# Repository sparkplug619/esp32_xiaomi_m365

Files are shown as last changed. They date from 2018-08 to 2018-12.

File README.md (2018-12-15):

attention - last update of this repo - i moved it to gitlab -> https://gitlab.com/esp32m365/esp32_xiaomi_m365_display

# esp32_xiaomi_m365
Sample Project for decoding serial bus data on a Xiaomi M365 Scooter on Espressif ESP32:
- Supports one or two 0.96" 128x64 SSD1306 based OLED screen(s)
- Display connectivity via i2c or spi (spi preffered as it's much faster)
- Firmwareupdates (of the ESP32) can be done over WiFi using ArduinoOTA, Scooterfirmwareupdates are not blocked, can be done the usual way
- Connects to known WiFi Networks or opens it's own SSID in AP Mode
- optional Telnet Servers for debugging
- Config Menu for changing scooter & esp settings
- Supports different Screen Languages, Miles/Kilometers, Wheel Sizes, 10/12s batteries
- Alerts for Low Battery, ESC, BMS Temperature, Cell-Voltage Monitoring,...
- displays speeds above 32.768km/h (set for speeds from 10km/h backwards to 55,44km/h forward, backwardspeed is displayed as a positive number)

# Details
- Telnet on Port 36523 with different Screens
- Telnet on Port 36524 with raw byte dump from M365 Bus ("read only")
- Telnet on Port 36525 with packet decode/dump from M365 Bus ("read only")
- M365 Serial Receiver and Packet decoder into Array per Address
- M365 Data Requestor obey the M365 Bus Timing, does not interfere with Xiaomi's Firmware-Flash process, but can be disabled in the menu (ESP Bus Mode = Passive)
- Data Requestor internally allows subscription to predefined groups of data (e.g. OLED display only needs Cell-Voltage Data when it's displayed) to reduce requested data and therefore get a higher update rate on the interesting data fields.
- Internal Timers/Counters for debugging Receiver/Requestor & Oled-Draw/Transfer Durations - see Telnet/36523 Statistics Screen
- Different Screens for Drive/Stop/Charge/Error/Firmwareupgrade/Locked State/Timeout-Screen
- Alerts: Background Task ("Housekeeper") periodically requests additional data from M365 and validates against tresholds (set in configmenu), shows alert-popup and increases alert-counters
- Popups on screen if alerts occur, alert-counters in data screens when stopped
- Scooter can be locked/unlocked/switched off from config-menu
- Custom Screens for
	- Driving
	- "Stopped" - multiple Data screens when not moving (swipe through them using throttle)
	- "Charging" - in single-screen configuration multiple screens while charging (swipe through them using throttle)
	- Config Menu (push Brake & Throttle at the same time to enter, select items using throttle, change/enter using brake)
 	- "LOCKED" screen mode when scooter has been locked

# Todos
 - add display-sleeptimer - x seconds after last event (gas/brake/throttle/speed/chargerun-plug/telnet/AP-Client Connection & speed = 0)

# Telnet / Debugging Interface
 - Telemetrie Screen shows decoded known values: Batt Voltage, Current, Speed,... 
 - Statistics Screen dumps some internal counters, e.g. Packet Counters, CRC Files, Timing,...
 - ESC/BLE/BMS/"X1" RAW Screens dumps the 512 Byte Array for each device (format "00 00 ...")

 use the letters
  - s,t,e,b,n,x to switch between the screens
  - r to reset statistics & zero m365 data arrays

# Wiring
## Connector in M365 Headunit
M365 has a Serial Data Bus over one Wire (UART in half-duplex mode) between BLE Module and ESC (Motor Controller) and we want to connect the ESP32 to that bus, as well as get Power from the Scooter.
The Connection between BLE-Module and ESC consists of 4 wires, the connection as seen on the BLE Module:
- Ground  (Black, "G")
- One Wire Serial Connection (Yellow, "T", 115200bps, 8n1)
- VBatt (Green, "P", always available)
- 5V (Red, "5", only when scooter is turned on)

## ESP32 Powering
ESP32 needs a Vcc of 3.3V, so you can wire the 5V from M365 to a Vreg for 3.3v which powers the ESP. DO NOT POWER THE ESP32 WITH 5V!

## M365 Serial Data Bus Connection

Other then the VCC which can not be 5V, the ESP32 GPIO Pins can be connected to 5V signals.
So the Serial RX & TX Pins can be directly connected, but to ensure communication on the one-wire uart bus we need 2, to be on the safe side 3 parts:
 - 680R or 1k between RX and M365 Data Bus
 - And a Diode from M365 Data Bus in series with a ~100-200R towards TX Pin of  ESP32
That way Hardware-UART on the ESP32 can be used.

## ESP32 Pin assignment

The ESP32 has a io-switchmatrix, so (nearly) any hardwareunit can be mapped to nearly any pin.
Just be sure to not to use:
 - GPIO_NUM_34 – GPIO_NUM_39 are only GPI - Input, NO OUTPUT, No Pullup or Pulldown!
 - GPIO 6-11 are used by flash - not usable
 - GPIO 0 is for boot/flashing with pullup

# PCB Bugs v180723
 - 1nF or 470pF C from EN towards GND and 12-18k R from EN towards 3.3V are missing (sad copy and paste error)
 - the SOT23 Diode housing might be wrong - depending on your Diode (BAS70xx versions) -> the Diode-Package can be rotated 120° CCW to fix that

# Before Compiling

## Choose your environment  (platformio):
  - PlatformIO supports different (build-)"Environments", you will mostly want to select "m365client" which implements the "client" for a stock m365 scooter and the oled display.
## PATCH your libraries!
  - Plattformio includes my patched Adafuit_SSD1306 library for you, if u are using a different ide, please look in platformio.ini for references to the patches libraries and make sure those are used. In the meanwhile Adafruit updated it's libraries to get rid of the problems, so one day i'll update my code to use the new lib from Adafruit and get rid of the patched libraries.
  - earlier code versions needed some files patched in arduino-esp32 framework in order for correct uart functionality. now i've included the patched UART-Files in this repo, so the patch in arduino-esp32 is not needed anymore (save you time and solves the problem that your other projects would also use that patched framework). But one day when arduino-esp32 framework get's updated this might brake and the files included in this project need to be updated.
  - unfortunately the latest update of platform-io included the arduino-esp32 framework with a broken i2c implementation. This needs to be patched manually, but it fixes a general problem, so this will help your other projects using i2c as well. For patching please see this issue and replace the 4 files as mentioned - otherwise the i2c-display will hang at most restarts: https://github.com/platformio/platform-espressif32/issues/126

## setup individual settings
### ssid's and passwords:
 - please open secrets.h and fill in your own ssid/passwords for client/ap mode and ota updates!
### setup for your hardware
 - copy one of my board*.h files that fits your hardware best, update it for your setup and include this file in definitions.h
 - when updating my code you just need to reapply the include of your boards file in definitions.h

# Support, Questions,...?
 - Telegram Group https://t.me/esp32brain4m365

# Credits & Thanks to
 - Paco Gorina for his research on the protocoll and packet structure (-> http://www.gorina.es/9BMetrics/)
 - CamiAlfa for his research and providing informations about the contents of the packets & arrays (-> https://github.com/CamiAlfa/M365-BLE-PROTOCOL)
 - french translation kindly provided by Technoo' Loggie (Telegram Handle @TechnooLoggie)

# Licensed under Creative Commons V4 - BY NC SA
 - THIS MEANS YOU CAN USE THIS CODE FOR NON COMMERCIAL PURPOSES, HAVE TO RESHARE YOUR MODIFICATIONS AND REFERENCE THIS REPO.

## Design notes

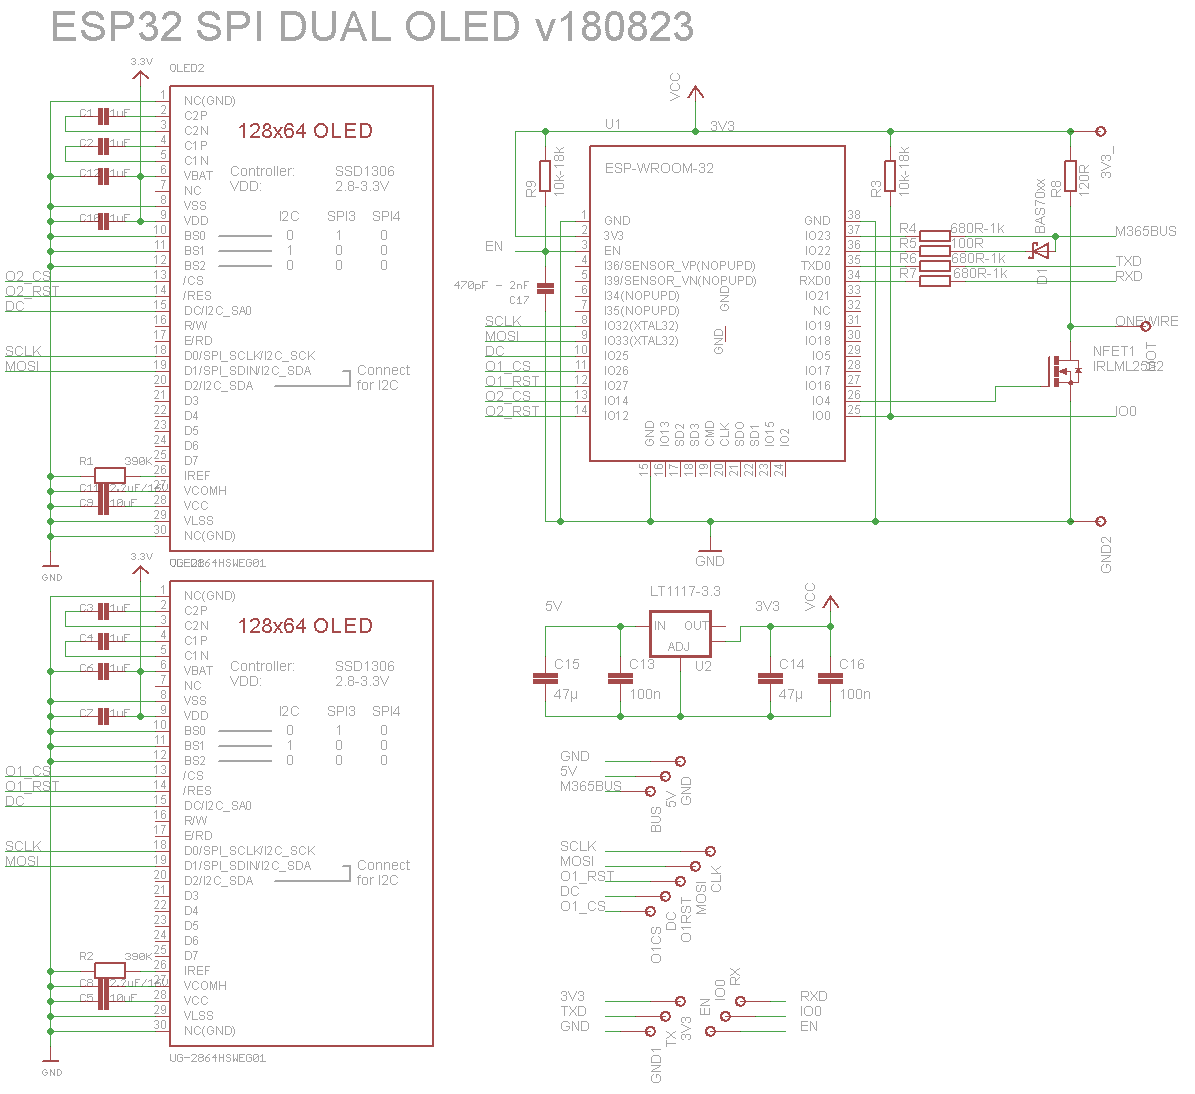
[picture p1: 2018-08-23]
schematics/esp32_ssd1306_schematic_v180823.png

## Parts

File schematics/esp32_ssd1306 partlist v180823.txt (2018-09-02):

Exported from esp32_ssd1306.sch v180823

Part     Value          Device                        Package                          Library              Sheet

ESP32:
U1       ESP-WROOM-32   ESP-WROOM-32                  ESP-WROOM-32                     esp32                1
R6       680R-1k        R-EU_R0805                    R0805                            rcl                  1
R7       680R-1k        R-EU_R0805                    R0805                            rcl                  1
R3       10k-18k        R-EU_R0805                    R0805                            rcl                  1
R9       10k-18k        R-EU_R0805                    R0805                            rcl                  1
C17      470pF - 2nF    CAP_CERAMIC0805               0805                             microbuilder         1

Voltage Regulator:
U2       LT1117-3.3     V_REG_LM1117SOT223            SOT223                           SparkFunEagle-6-6-07 1
C13      100n           C-EUC0805K                    C0805K                           rcl                  1
C14      47µ            C-EUC1210K                    C1210K                           rcl                  1
C15      47µ            C-EUC1210K                    C1210K                           rcl                  1
C16      100n           C-EUC0805K                    C0805K                           rcl                  1

M365 Connection:
R4       680R-1k        R-EU_R0805                    R0805                            rcl                  1
R5       100R           R-EU_R0805                    R0805                            rcl                  1
D1       BAS70xx        BAS70                         SOT23                            diode                1

Needed for OLED Display Connector soldered directly to PCB on Connector OLED1:
OLED1    UG-2864HSWEG01 DISP_OLED_UG-2864HSWEG010.96" UG-2864HSWEG01_0.96IN_WRAPAROUND ssd1306              1
R2       390K           RESISTOR0805                  0805                             microbuilder         1
C3       1uF            CAP_CERAMIC0805               0805                             microbuilder         1
C4       1uF            CAP_CERAMIC0805               0805                             microbuilder         1
C6       1uF            CAP_CERAMIC0805               0805                             microbuilder         1
C7       1uF            CAP_CERAMIC0805               0805                             microbuilder         1
C5       10uF           CAP_CERAMIC0805               0805                             microbuilder         1
C8       2.2uF/16V      CAP_CERAMIC0805               0805                             microbuilder         1

Needed for OLED Display Connector soldered directly to PCB on Connector OLED2:
OLED2    UG-2864HSWEG01 DISP_OLED_UG-2864HSWEG010.96" UG-2864HSWEG01_0.96IN_WRAPAROUND ssd1306              1
R1       390K           RESISTOR0805                  0805                             microbuilder         1
C1       1uF            CAP_CERAMIC0805               0805                             microbuilder         1
C2       1uF            CAP_CERAMIC0805               0805                             microbuilder         1
C12      1uF            CAP_CERAMIC0805               0805                             microbuilder         1
C9       10uF           CAP_CERAMIC0805               0805                             microbuilder         1
C10      1uF            CAP_CERAMIC0805               0805                             microbuilder         1
C11      2.2uF/16V      CAP_CERAMIC0805               0805                             microbuilder         1

Optional (not implemented in Firmware) for Temperature Sensor (1-wire or analog):
NFET1    IRLML2502      IRLML2502                     MICRO3                           transistor-power     1
R8       120R           R-EU_R0805                    R0805                            rcl                  1

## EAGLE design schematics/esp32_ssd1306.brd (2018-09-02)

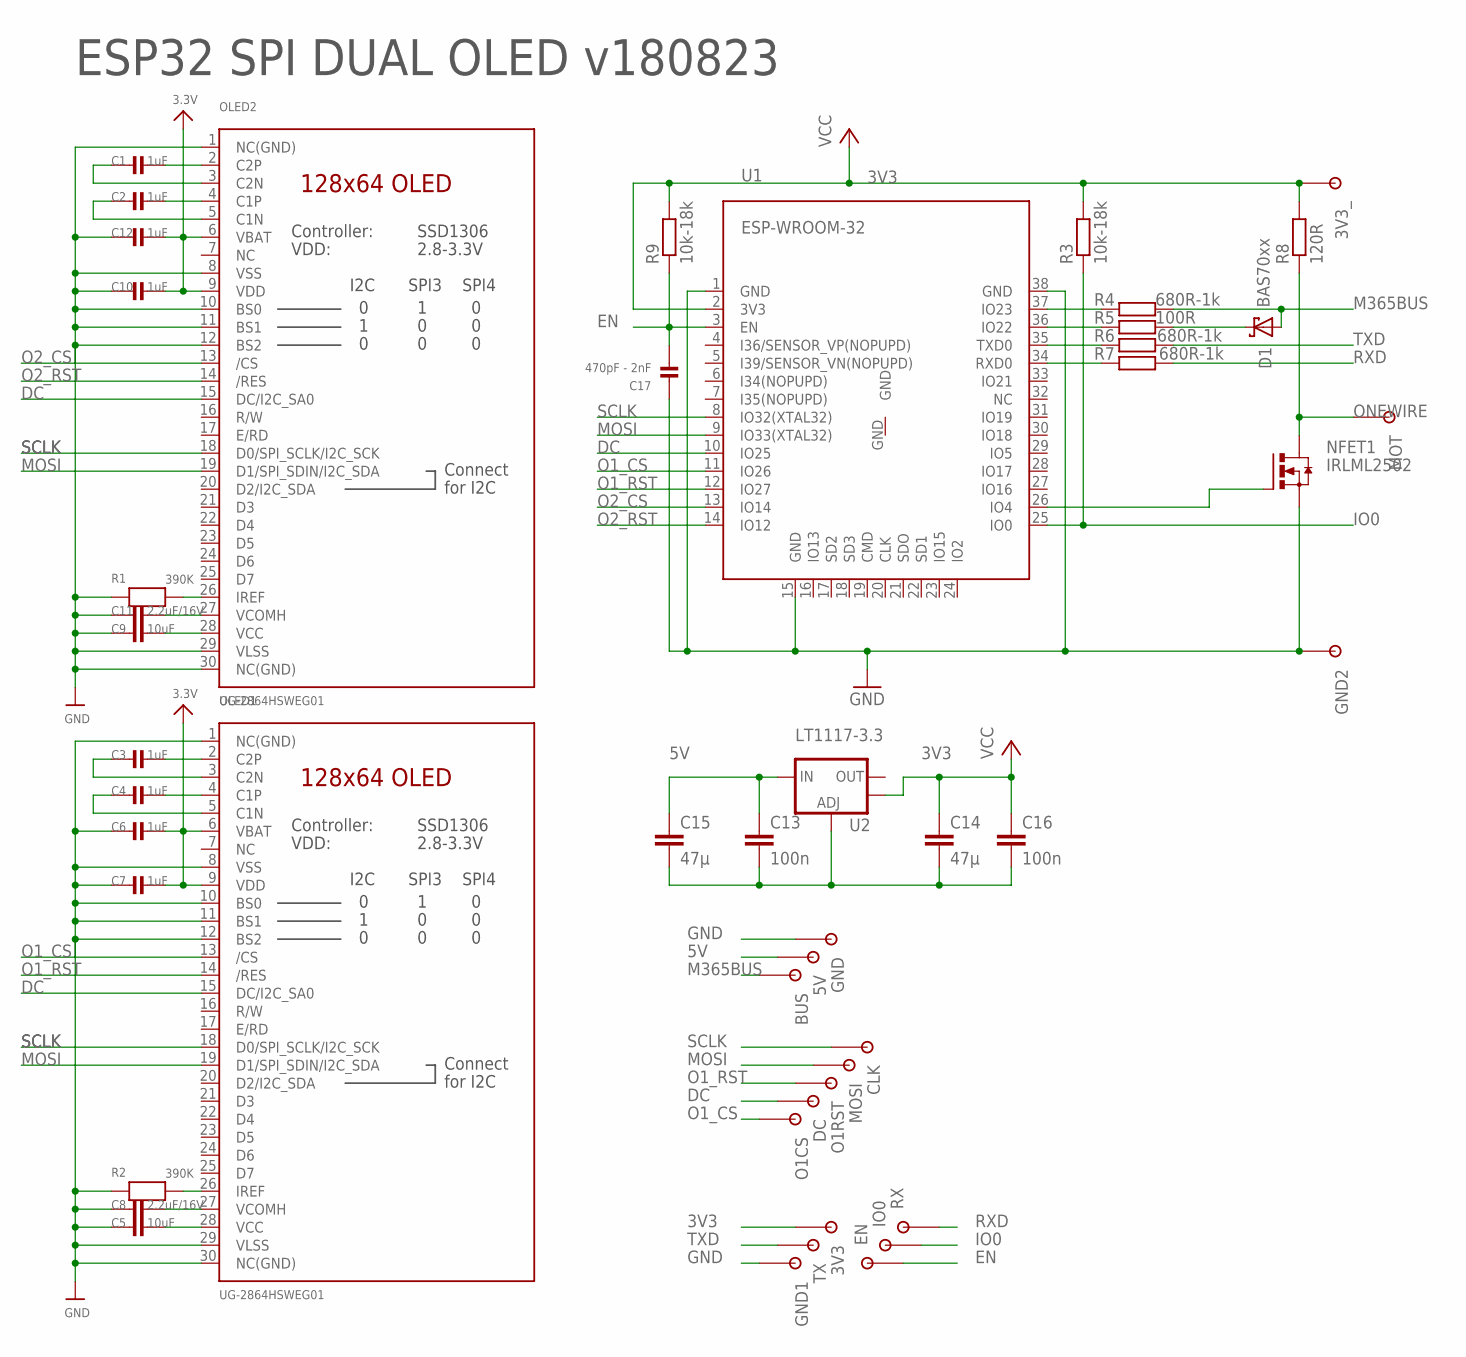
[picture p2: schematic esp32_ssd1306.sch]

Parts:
3V3, 3V3_, 5V: PAD1
BUS: PAD1
C1, C2, C3, C4, C6, C7, C10, C12: 1uF; 0805
C5, C9: 10uF; 0805
C8, C11: 2.2uF/16V; 0805
C13, C16: 100n; C0805K
C14, C15: 47µ; C1210K
C17: 470pF - 2nF; 0805
CLK: PAD1
D1: BAS70xx; SOT23
DC: PAD1
EN: PAD1
GND, GND1, GND2: PAD1
IO0: PAD1
MOSI: PAD1
MOT: PAD1
NFET1: IRLML2502; MICRO3
O1CS, O1RST: PAD1
OLED1, OLED2: UG-2864HSWEG01; UG-2864HSWEG01_0.96IN_WRAPAROUND
R1, R2: 390K; 0805
R3, R9: 10k-18k; R0805
R4, R6, R7: 680R-1k; R0805
R5: 100R; R0805
R8: 120R; R0805
RX: PAD1
TX: PAD1
U1: ESP-WROOM-32
U2: LT1117-3.3; SOT223

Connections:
3V3: 3V3.P$1, 3V3_.P$1, C6.2, C7.2, C10.2, C12.2, C14.1, C16.1, OLED1.6 (VBAT), OLED1.9 (VDD), OLED2.6 (VBAT), OLED2.9 (VDD), R3.2, R8.2, R9.2, U1.2 (3V3), U2.4 (OUT)
5V: 5V.P$1, C13.1, C15.1, U2.3 (IN)
DC: DC.P$1, OLED1.15 (DC/I2C_SA0), OLED2.15 (DC/I2C_SA0), U1.10 (IO25)
EN: C17.2, EN.P$1, R9.1, U1.3 (EN)
GND: C5.1, C6.1, C7.1, C8.1, C9.1, C10.1, C11.1, C12.1, C13.2, C14.2, C15.2, C16.2, C17.1, GND.P$1, GND1.P$1, GND2.P$1, NFET1.2 (S), OLED1.1 (NC(GND)), OLED1.8 (VSS), OLED1.10 (BS0), OLED1.11 (BS1), OLED1.12 (BS2), OLED1.29 (VLSS), OLED1.30 (NC(GND)), OLED2.1 (NC(GND)), OLED2.8 (VSS), OLED2.10 (BS0), OLED2.11 (BS1), OLED2.12 (BS2), OLED2.29 (VLSS), OLED2.30 (NC(GND)), R1.1, R2.1, U1.1 (GND), U1.15 (GND), U1.38 (GND), U2.1 (ADJ)
IO0: IO0.P$1, R3.1, U1.25 (IO0)
M365BUS: BUS.P$1, D1.1 (A), R4.2
MOSI: MOSI.P$1, OLED1.19 (D1/SPI_SDIN/I2C_SDA), OLED2.19 (D1/SPI_SDIN/I2C_SDA), U1.9 (IO33(XTAL32))
unnamed: OLED2.26 (IREF), R1.2
unnamed: C1.2, OLED2.2 (C2P)
unnamed: OLED1.26 (IREF), R2.2
unnamed: C3.2, OLED1.2 (C2P)
unnamed: C3.1, OLED1.3 (C2N)
unnamed: C4.2, OLED1.4 (C1P)
unnamed: C4.1, OLED1.5 (C1N)
unnamed: C1.1, OLED2.3 (C2N)
unnamed: C2.2, OLED2.4 (C1P)
unnamed: C2.1, OLED2.5 (C1N)
unnamed: C5.2, OLED1.28 (VCC)
unnamed: C8.2, OLED1.27 (VCOMH)
unnamed: C9.2, OLED2.28 (VCC)
unnamed: C11.2, OLED2.27 (VCOMH)
unnamed: D1.3 (C), R5.2
unnamed: NFET1.1 (G), U1.26 (IO4)
unnamed: R4.1, U1.37 (IO23)
unnamed: R5.1, U1.36 (IO22)
unnamed: R6.1, U1.35 (TXD0)
unnamed: R7.1, U1.34 (RXD0)
O1_CS: O1CS.P$1, OLED1.13 (/CS), U1.11 (IO26)
O1_RST: O1RST.P$1, OLED1.14 (/RES), U1.12 (IO27)
O2_CS: OLED2.13 (/CS), U1.13 (IO14)
O2_RST: OLED2.14 (/RES), U1.14 (IO12)
ONEWIRE: MOT.P$1, NFET1.3 (D), R8.1
RXD: R7.2, RX.P$1
SCLK: CLK.P$1, OLED1.18 (D0/SPI_SCLK/I2C_SCK), OLED2.18 (D0/SPI_SCLK/I2C_SCK), U1.8 (IO32(XTAL32))
TXD: R6.2, TX.P$1

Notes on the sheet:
ESP32 SPI DUAL OLED v180823

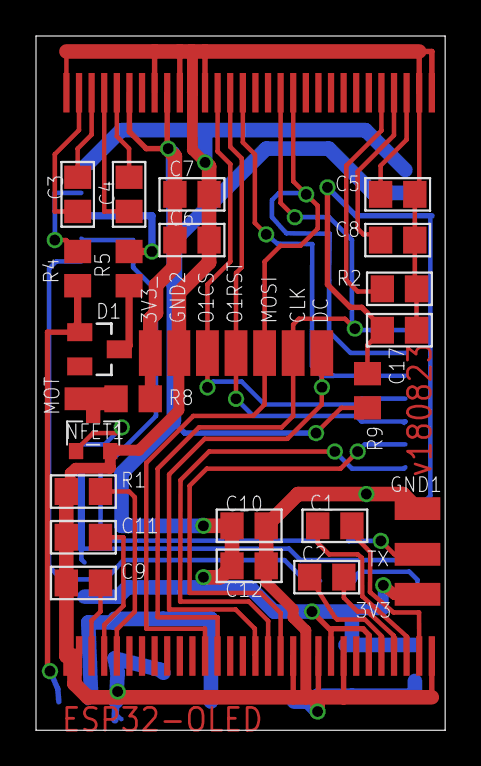
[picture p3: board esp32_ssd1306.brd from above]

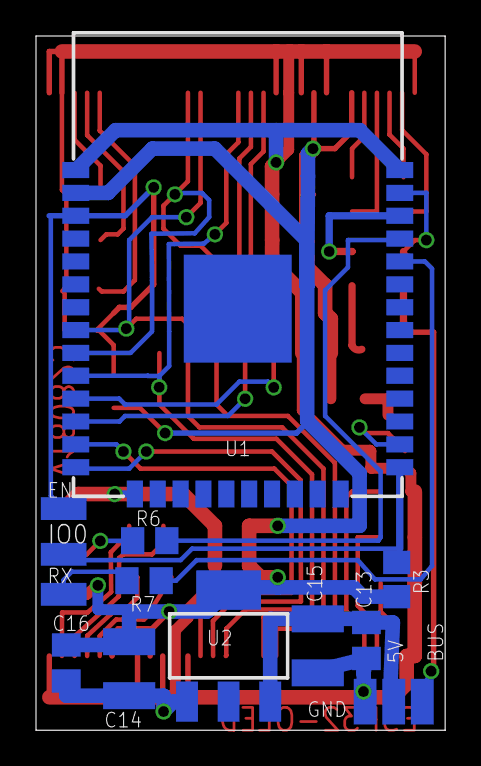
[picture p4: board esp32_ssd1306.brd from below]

Board: 2 copper layers, 22.7 x 38.6 mm, 49 parts (17 on the bottom side), 36 nets.

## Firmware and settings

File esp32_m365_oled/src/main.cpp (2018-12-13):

/*  ESP32 M365
 * see readme.md for details
 *
 * configuration adoptions should be done in definitions.h
 * secrets.h must be created (see readme.md)
 * boards.h can be created to store your hardware-setup locally and keep it when updates are rolling in (see readme.md)
 * language adoptions in strings.h - i'm happy to add new languages/translations from you ;)
 *
 * needs patch in esp32-arduino-core/esp32-hal-uart.c (112 byte hardware uart-receive buffer is to big for "realtime" communication)
 *  -> see comments in definitions.h / readme.md and patch yourself or use https://github.com/smartinick/arduino-esp32
 * for now this has to be done locally on your dev machine
 *
 * needs patched Adafruit_SSD1306 Library (patched fork see https://github.com/smartinick/Adafruit_SSD1306)
 * platformio.ini is configured to use this library - no user interaction needed
 *
 * known BUGS: 
 * - apssid/appassword not applied when switching from client-mode/search to AP
 * - does not receive/decode all data after doing OTA, reboot once and it works
 * - "beep" command does not work in current version
 */

#include "definitions.h"
#include "config.h"
#include "strings.h"
#include "wlan.h"
#ifdef headunit
  #include "m365headunit.h"
#else
  #include "m365client.h"
#endif
#ifdef usedisplay
  #include "display.h"
#endif
#ifdef usengcode
  #include "ngcode.h"
#endif
#ifdef usetelnetserver
  #include "telnet.h"
#endif

#ifdef usestatusled
  int ledontime = 0;
  int ledofftime = 10000;
  unsigned long ledcurrenttime = 100;
#endif

//generic temp  vars
  uint8_t i;
  char tmp1[200];
  char tmp2[200];

//timing & statistics
  unsigned long duration_mainloop=0;
  unsigned long timestamp_mainloopstart=0;
  unsigned long duration_oled=0;
  unsigned long timestamp_oledstart=0;
  unsigned long duration_oled1draw=0;
  unsigned long timestamp_oled1draw=0;
  unsigned long duration_oled1transfer=0;
  unsigned long timestamp_oled1transfer=0;
  unsigned long duration_oled2draw=0;
  unsigned long timestamp_oled2draw=0;
  unsigned long duration_oled2transfer=0;
  unsigned long timestamp_oled2transfer=0;
  unsigned long duration_telnet=0;
  unsigned long timestamp_telnetstart=0;
  unsigned long timestamp_showsplashscreen=0;

HardwareSerialPatched m365uart(2);

boolean pcflag = true;

#ifdef headunit
  M365Headunit *ptrm365bus = new M365Headunit();
#else
  M365Client *ptrm365bus = new M365Client();
#endif
#ifdef usedisplay
  M365Display *ptrm365d = new M365Display();
#endif

/*
//define
      #define throttlemindefault 40
      #define throttlemaxdefault 190
      uint8_t throttlemin = throttlemindefault;
      uint8_t throttlemax = throttlemaxdefault;


//setup:
  

//loop: if newdata from "x1"
  from updatestats:
    1st block
      if (bleparsed->throttle!=0) {
        if (throttlemin>bleparsed->throttle) { 
          throttlemin=bleparsed->throttle; 
          stopwindowsize = (uint8_t)((throttlemax-throttlemin)/stopsubscreens);
          chargewindowsize = (uint8_t)((throttlemax-throttlemin)/chargesubscreens);
          configwindowsize = (uint8_t)((throttlemax-throttlemin)/(configsubscreens-1));
        }
        if (throttlemax<bleparsed->throttle) { 
          throttlemax=bleparsed->throttle;
          stopwindowsize = (uint8_t)((throttlemax-throttlemin)/stopsubscreens);
          chargewindowsize = (uint8_t)((throttlemax-throttlemin)/chargesubscreens);
          configwindowsize = (uint8_t)((throttlemax-throttlemin)/(configsubscreens-1));
        }
      }
    2nd block:
      if (alert_lockedalarm)
          alertpopup((char*)"ALARM", (char*)"SCOOTER LOCKED!", popupalertduration);
      }
  



*/
#ifdef usestatusled
  void handle_led() {
    if (ledontime==0) { 
      digitalWrite(led,LOW); 
    } else {
      if (ledofftime==0) { 
        digitalWrite(led,HIGH); 
      } else {
        if (millis()>ledcurrenttime) {
          if (digitalRead(led)) {
            digitalWrite(led,LOW);
            ledcurrenttime = millis()+ledontime;
          } else {
            digitalWrite(led,HIGH);
            ledcurrenttime = millis()+ledofftime;
          } //else digitalread
        } //if millis
      } //else ledoff
    } //else ledon
  }//handle_led
#endif

#ifdef debug_dump_states //dump state machine states to Serial Port on change
  void print_states() {
    #ifdef usetelnetserver    
      if (telnetstate!=telnetstateold) {
        DebugSerial.printf("### TELNETSTATE %d -> %d\r\n",telnetstateold,telnetstate);
        telnetstateold=telnetstate;
      }
    #endif    
    if (ptrm365bus->m365receiverstate!=ptrm365bus->m365receiverstateold) {
      DebugSerial.printf("### M365RecState: %d -> %d\r\n",ptrm365bus->m365receiverstateold,ptrm365bus->m365receiverstate);
      ptrm365bus->m365receiverstateold=ptrm365bus->m365receiverstate;
    }
    if (ptrm365bus->m365packetstate!=ptrm365bus->m365packetstateold) {
      DebugSerial.printf("M365PacketState: %d -> %d\r\n",ptrm365bus->m365packetstateold,ptrm365bus->m365packetstate);
      ptrm365bus->m365packetstateold=ptrm365bus->m365packetstate;
    }    
  } //print_states
#endif

void printconfiguration() {
  DebugSerial.println("Using ESP32 Configuration:");
  #ifdef usengfeatuart
    DebugSerial.printf("# UART Mode: IO/1/2: %d/%d/%d\r\n",M365SerialGPIO, M365SerialSpareRX, M365SerialSpareTX);
  #else
    DebugSerial.printf("# UART Mode: RX/TX: %d/%d\r\n",UART2RX, UART2TX);
  #endif
  #ifdef usedisplay
    DebugSerial.println("# Display Configuration"); 
      #ifdef LANGUAGE_EN
        DebugSerial.println("#  Language: English");
      #endif
      #ifdef LANGUAGE_FR
        DebugSerial.println("#  Language: French");
      #endif
      #ifdef LANGUAGE_DE
        DebugSerial.println("#  Language: German");
      #endif
      #ifdef usei2c
        DebugSerial.printf("#  Mode: I2C, SDA: %d, SCL: %d, Reset: %d, doReset: %d, Clock: %lu\r\n", oled_sda, oled_scl,oled_reset, oled_doreset, oled_clock);
        #ifdef useoled1
          DebugSerial.printf("#  display1: Address: 0x%02x, Rotation: %d\r\n", oled1_address, OLED1_ROTATION);
        #endif
        #ifdef useoled2
          DebugSerial.printf("#  display2: Address: 0x%02x, Rotation: %d\r\n", oled2_address, OLED2_ROTATION);
        #endif
      #else
        DebugSerial.printf("#  Mode: SPI, MiSo: %d, MoSi: %d, Clk: %d, DC: %d, Clock: %lu\r\n", OLED_MISO,OLED_MOSI,OLED_CLK,OLED_DC,oled_clock);
        #ifdef useoled1
          DebugSerial.printf("#  display1: CS: %d, Rst: %d, Rotation: %d\r\n", OLED1_CS, OLED1_RESET, OLED1_ROTATION);
        #endif
        #ifdef useoled2
          DebugSerial.printf("#  display2: CS: %d, Rst: %d, Rotation: %d\r\n", OLED2_CS, OLED2_RESET, OLED2_ROTATION);
        #endif
      #endif
    DebugSerial.printf("#  Display Core %d, Prio %d\r\n",core_display,prio_display);
  #else
    DebugSerial.println("# Display disabled"); 
  #endif    
  #ifdef headunit
    DebugSerial.println("# Controller Config:");
    DebugSerial.printf("#  UART Core %d, Prio %d\r\n",core_uart,prio_uart);
    DebugSerial.printf("#  Main Core %d, Prio %d\r\n",xPortGetCoreID(), uxTaskPriorityGet(NULL));
    DebugSerial.printf("#  WiFi Core %d, Prio %d\r\n",wificore, wifiprio);
    DebugSerial.printf("#  ADC GPIO: Gas: %d, Throttle %d\r\n", sensor_brake, sensor_throttle);
    DebugSerial.printf("#  ADC Min: %d, Max %d\r\n", adcmin, adcmax);
    DebugSerial.printf("#  ESC Min: %d, Max %d\r\n", sensormin, sensormax);
    #ifdef debuggpio1
      DebugSerial.printf("#  Debug GPIO1: %d, GPIO2: %d\r\n", debuggpio1, debuggpio2);
    #endif
  #else
    DebugSerial.println("# Controller disabled");
  #endif
  #ifdef debuguarttiming
    DebugSerial.printf("# UART Timing Debug Pin: %d\r\n", M365debugtx);
  #else
    DebugSerial.println("# UART Timing Debug disabled");
  #endif
  #ifdef usetelnetserver
    DebugSerial.printf("# TelnetServer @ TCP Port %d\r\n", telnet_port_statistics);
  #endif
  #ifdef usepacketserver
    DebugSerial.printf("# PacketServer @ TCP Port %d\r\n", telnet_port_packet);
  #endif
  #ifdef userawserver
    DebugSerial.printf("# RAWServer @ TCP Port %d\r\n", telnet_port_raw);
  #endif
  DebugSerial.println("\r\nUsing M365 Configuration:");
  printconfig();
  DebugSerial.println("");
  DebugSerial.println("\r\nDebug NVS Config:");
  printnvsconfig();
  DebugSerial.println("");


}

void setup() {
  loadconfig();
  DebugSerial.begin(115200);
  m365uart.begin(115200,SERIAL_8N1, UART2RX, UART2TX);
  #ifdef usedisplay
    ptrm365d->begin(ptrm365bus);
  #endif
  #ifdef usengcode
    init_ng();
  #else
    DebugSerial.printf("\r\n\r\n\r\nESP32 M365 %s\r\n",swversion);
  #endif
  #ifdef usedisplay
    ptrm365bus->begin(&m365uart, ptrm365d); //start_m365();
  #else
    ptrm365bus->begin(&m365uart); //start_m365();
  #endif
  #ifdef usestatusled
    pinMode(led,OUTPUT);
    digitalWrite(led,LOW);
  #endif
  //printconfiguration();
  if (conf_espwifionstart) {
    wlanstate=wlanturnstaon;
  }
  pcflag = true;
} //setup


void loop() {
  timestamp_mainloopstart=micros();
  handle_wlan();
  if (((wificore!=255) & (pcflag)) | !conf_espwifionstart) {
    printconfiguration();
    pcflag = false;
  }
  #ifdef usetelnetserver
    handle_telnet();
  #endif
  #ifdef usengcode
    loop_ng1();
  #endif
  ptrm365bus->loop();
  #ifdef usedisplay
    //ptrm365d->loop();
  #endif
  #ifdef usestatusled
    handle_led();
  #endif
  #ifdef debug_dump_states
    print_states();
  #endif
  duration_mainloop=micros()-timestamp_mainloopstart;
}

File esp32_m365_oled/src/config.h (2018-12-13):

#ifndef CONFIG_h
#define CONFIG_h

#include "definitions.h"

#include <Preferences.h>

extern Preferences preferences;

  #define wheelfact8km 1.0f
  #define wheelfact8miles  0.621371192f
  #define wheelfact10km    1.176470588f
  #define wheelfact10miles 0.731024932f

//scooter-config stuff
	extern uint8_t conf_wheelsize;
	extern uint8_t conf_battcells;
	extern uint8_t conf_alert_batt_celldiff;
	extern uint8_t conf_alert_batt_temp;
	extern uint8_t conf_alert_batt_voltage;
	extern uint8_t conf_alert_esc_temp;
	extern uint8_t conf_unit;
	extern bool conf_flashprotect;
	extern bool conf_espbusmode;
	extern bool conf_espwifionstart;
	extern bool conf_beeponalert;

	extern float wheelfact;

//display config
	extern bool conf_usedisplay;
	extern bool conf_usedisplay1;
	extern bool conf_usedisplay2;
	extern bool conf_display_i2cspi; //true = i2c, false = spi

	extern int8_t conf_display_i2c_gpio_data;
	extern int8_t conf_display_i2c_gpio_clock;
	extern int8_t conf_display_i2c_gpio_reset;
	extern bool conf_display_i2c_doreset;
	extern uint32_t conf_display_i2c_clockspeed;
	extern int8_t conf_display_spi_gpio_miso;
	extern int8_t conf_display_spi_gpio_mosi;
	extern int8_t conf_display_spi_gpio_clk;
	extern int8_t conf_display_spi_gpio_dc;
	extern uint32_t conf_display_spi_clockspeed;
	
	extern int8_t conf_display1_i2c_address;
	extern int8_t conf_display1_spi_gpio_cs;
	extern int8_t conf_display1_spi_gpio_reset;
	extern int8_t conf_display1_rotation;
	extern int8_t conf_display2_i2c_address;
	extern int8_t conf_display2_spi_gpio_cs;
	extern int8_t conf_display2_spi_gpio_reset;
	extern int8_t conf_display2_rotation;

//uart config
	extern int8_t conf_uart_gpio_rx;
	extern int8_t conf_uart_gpio_tx;

//misc config
	extern int8_t conf_led_gpio;
	extern int8_t conf_gpio_debug1;
	extern int8_t conf_gpio_debug2;


void applyconfig(void);
void loadconfig(void);
void saveconfig(void);
void printconfig(void);
void printnvsconfig(void);
 
#endif

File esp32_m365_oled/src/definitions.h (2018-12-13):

#ifndef DEFINITIONS_h
#define DEFINITIONS_h

#include "Arduino.h"

//see readme.md -> put your wifi/ota passwords in secrects.h!
//#include "secrets.h"

//hardware setup
  //see readme.md -> you can add your own boards*.h file to keep your hardware-setup save when upgrading the code

  #include "boards_smartinick_ttgo.h"
  //#include "boards_smartinick_wemos.h"
  //#include "boards_smartinick_pcb180723spidual.h"
  //#include "boards_smartinick_pcb180723i2csingle.h"


//define screen language
  #define LANGUAGE_EN
  //#define LANGUAGE_FR //translation kindly provided by Technoo' Loggie (Telegram Handle @TechnooLoggie)
  //#define LANGUAGE_DE

//turn on/off minor features
  //#define staticip //use static IP in Client Mode, Comment out for DHCP, IP is defined in boards*.h file
  //#define usestatusled //Status LED? GPIO defined in boards*.h

//define which functional modules we use, uncomment to disable:
  //#define headunit //replace BLE Module
  //#define hudisplaydebug //activate debug dislplay for sensor readings,...
  //#define usedisplay

  //#define usetelnetserver //enable telnet dashboard server, port defined below
  //#define usepacketserver //enable telnet packet server, port defined below
  //#define userrawserver //enable telnet raw data server, port defined below

//DEBUG Settings
  //#define debug_dump_states //dump state machines state
  //#define debug_dump_rawpackets //dump raw packets to Serial/Telnet
  //#define debug_dump_packetdecode //dump infos from packet decoder
  
//usually nothing has to be changed below

//#define usengcode
#ifdef usengcode
  #include "ngcode.h"
#endif

#define swversion "v2.0.0"

//Serial UART Setup for Debugging and M365 Connection
  #define DebugSerial Serial //Debuguart = default Serial Port/UART0
  
//helpers
  #define _max(a,b) ((a)>(b)?(a):(b))
  #define _min(a,b) ((a)<(b)?(a):(b))

//timing
  #define m365packettimeout  500 //timeout in ms after last received packet for showing connection-error
  #define housekeepertimeout 3000 //duration between housekeeper-datarequests
  #define splashscreentimeout 3000 //how long to show splashscreen on power-up
  #define wlanconnecttimeout 10000 //timeout for connecting to one of  the known ssids
  #define wlanapconnecttimeout 600000 //timeout in ap mode until client needs to connect / ap mode turns off

//telnet ports
  #ifdef usetelnetserver
    #define telnet_port_statistics 36523
  #endif
  #ifdef usepacketserver
    #define telnet_port_packet 36525
  #endif
  #ifdef userrawserver  
    #define telnet_port_raw 36524
  #endif

//just some checks of the above defines, don't change anything below!
//if something is wrong with the above defined things the next lines will throw an error
//solution is to fix the error in the defines above!

  #ifndef ESP32
    #error "Only ESP32 Plattform supported!"
  #endif
  //OLED
  #if (defined usedisplay && !defined useoled1)
    #error "usedisplay defined but useoled1 not defined!"
  #endif

  #if (!defined useoled1 && defined useoled2)
      #error "useoled2 defined, but useoled1 not defined"
  #endif

  #if (!defined ESP32 && !defined usei2c)
      #error "Hardware SPI only tested on ESP32!!!"
  #endif

  #ifndef usetelnetserver
    #ifdef usepacketserver
      #error "packetserver requires telnetserver"
    #endif
    #ifdef userawserver
      #error "rawserver requires telnetserver"
    #endif
  #endif

  #ifndef headunit
    #ifdef hudisplaydebug
      #error "hudisplaydebug requires headunit"
    #endif
  #endif


#endif

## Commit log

2018-07-26 reorganized/updated status screens, new charging screen
2018-07-31 screenformating done, minor bugfixing
    [esp32_m365_oled.ino]
2018-08-18 adopted GPIOs for PCB v180723, added SPI for faster display updates
2018-08-23 added schematics v180823
    [esp32_ssd1306.brd, esp32_ssd1306.sch]
2018-08-28 added i2c/spi clock speed for updated ssd1306 library, fixed some minor stuff, added Stauts display to trip (stop) screen
    [esp32_m365_oled.ino]
2018-08-29 added support for 10" wheels
2018-08-30 added chargedcapacity, updated charging-screen layout, added some menu handling stuff
2018-08-31 fixed oled1_rotation definition location
    [esp32_m365_oled.ino]
2018-09-02 fixed airwire
    [esp32_ssd1306.brd]
2018-09-06 fixed some minor bugs, worked on config menu
    [esp32_m365_oled.ino]
2018-09-07 implemented batt/wheel/busmode, fixed wifi-ap bug
    [esp32_m365_oled.ino]
2018-09-12 config menu start now via brake & throttle press, reorg of stopsubscreens
2018-09-17 fixed handling of "bothbutton", added oledreinit for fix of sometimes screwed display content
    [esp32_m365_oled.ino]
2018-10-08 added locked-screen, cleaned up mixed fonts, fixed power-display casting error
    [esp32_m365_oled.ino]
2018-10-19 fixed drivescreen current/watt casting
    [esp32_m365_oled.ino]
2018-10-21 finished menu display, value changing, implemented throttle min/max learning, fixed alert-treshold comparison for cell-voltage-difference-alert... ...
    [esp32_m365_oled.ino]
2018-10-21 fixed throttlemin / screen-navigation error
    [esp32_m365_oled.ino]
2018-10-21 fixed charging display while scooter is locked
    [esp32_m365_oled.ino]
2018-10-21 added battery low voltage alarm to configmenu
2018-10-21 change popup to alert & info popup configmenu: added option to beep on alert (for alertpopup) changed commandsending methods for esc & x1 commands fixed alerts on startup (as long as no values have b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
    [esp32_m365_oled.ino]
2018-10-24 shortened strings, moved value-edit dialog to 2nd screen on dualscreensetup, added configmenu autoexit if speed > 5km/h, minor changed to screen-switching conditions
    [esp32_m365_oled.ino]
2018-10-24 disabled popupdisplay while changing values, fixed menu-navigation-lock while changing values
    [esp32_m365_oled.ino]
2018-11-01 fixed formating bug on 2nd oled display/assets screen
    [display.cpp]
2018-11-03 semi-working onewire uart
2018-11-07 added info about boards.h, added secrets.h
2018-11-10 switched to plattformio style
2018-12-13 added boards definition files
2018-12-13 updated config with gpio definitions, currently unused (waiting for webserver feature)
2018-12-13 added patched uart files from arduino-esp32 - this repo does not need a patched arduino-esp32 framework anymore.
